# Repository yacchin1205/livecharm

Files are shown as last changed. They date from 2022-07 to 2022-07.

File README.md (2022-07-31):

# このリポジトリについて

*TBD*

# 必要パーツ

- Adafruit Feather RP2040 - ¥2,211
  https://www.switch-science.com/catalog/7216/
- リチウムイオンポリマー電池110mAh - ¥1,094
  https://www.switch-science.com/catalog/3166/
- MAX98357A搭載 I2S 3W D級アンプボード - ¥1,309
  https://www.switch-science.com/catalog/2749/
- uxcell オーバル 1W 8オーム マグネットスピーカー 4個 - ¥628
  https://www.amazon.co.jp/gp/product/B017IIV8KM/ 
- KKHMF TTP223 静電容量式 タッチスイッチ 10個 - ¥539
  https://www.amazon.co.jp/gp/product/B079BKVT98/

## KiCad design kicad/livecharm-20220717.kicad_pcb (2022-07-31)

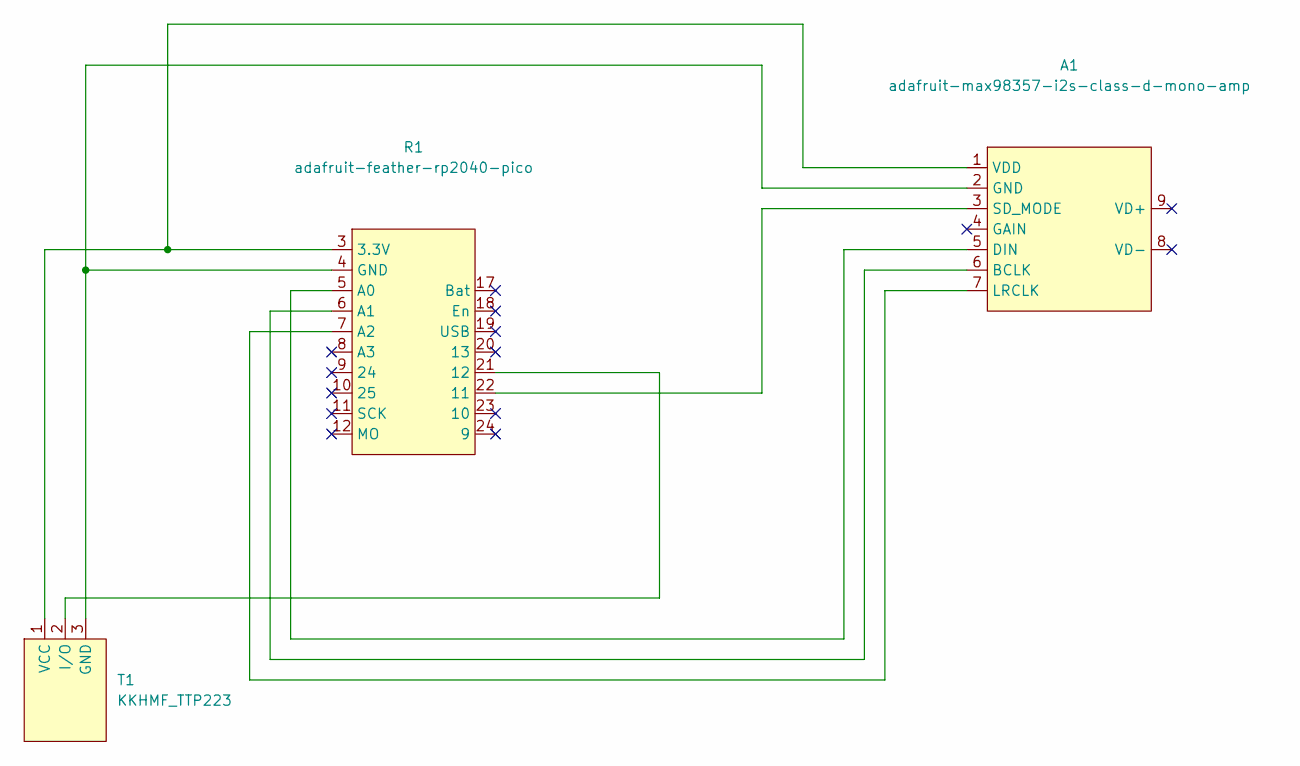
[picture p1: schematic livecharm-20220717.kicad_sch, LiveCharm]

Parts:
A1: adafruit-max98357-i2s-class-d-mono-amp
R1: adafruit-feather-rp2040-pico
T1: KKHMF_TTP223

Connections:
unnamed: A1.1 (VDD), R1.3 (3.3V), T1.1 (VCC)
unnamed: A1.2 (GND), R1.4 (GND), T1.3 (GND)
unnamed: A1.3 (SD_MODE), R1.22 (11)
unnamed: A1.5 (DIN), R1.5 (A0)
unnamed: A1.6 (BCLK), R1.6 (A1)
unnamed: A1.7 (LRCLK), R1.7 (A2)
unnamed: R1.21 (12), T1.2 (I/O)

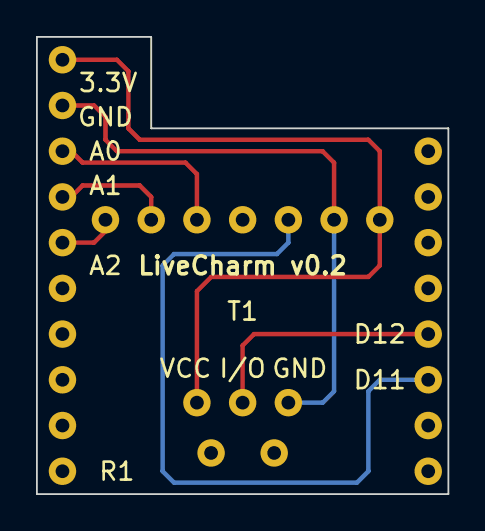
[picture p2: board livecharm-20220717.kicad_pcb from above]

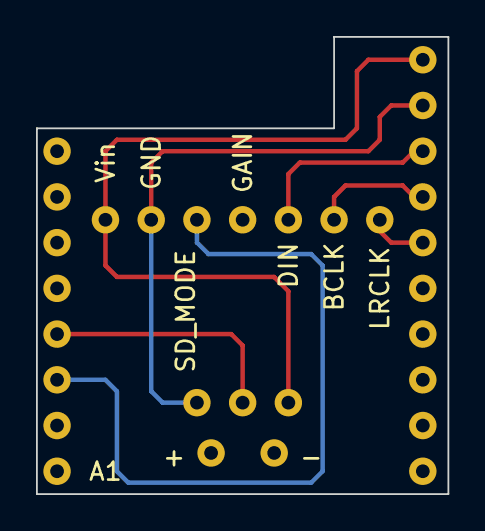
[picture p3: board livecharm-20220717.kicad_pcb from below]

Board: 2 copper layers, 22.9 x 25.4 mm, 3 parts (2 on the bottom side), 7 nets.

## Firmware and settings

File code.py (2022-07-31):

import digitalio
import audiocore
import audiopwmio
import board
import array
import time
import math
import os
import alarm
import audiobusio
import random
import re
import errno

DEFAULT_LIGHT_WAKEUP_SEC = 30
MAX_SLEEP_COUNT = 20
AUDIO_DIR = './audio'

# ---- Interface関係の定義
WAKE_PIN = board.D12
SHUTDOWN_PIN = board.D11

def open_dac():
    # Feather RP2040
    return audiobusio.I2SOut(board.A1, board.A2, board.A0)

# ---- Deep Sleep関係の処理
def get_pin_alarm():
    return alarm.pin.PinAlarm(pin=WAKE_PIN, value=True, pull=True)

def enter_deep_sleep():
    pin_alarm = get_pin_alarm()
    alarm.exit_and_deep_sleep_until_alarms(pin_alarm)
    # Deep Sleep後は続行されない

# ---- Light Sleep関係の処理
def enter_light_sleep():
    pin_alarm = get_pin_alarm()
    time_alarm = alarm.time.TimeAlarm(monotonic_time=time.monotonic() + DEFAULT_LIGHT_WAKEUP_SEC)
    triggered_alarm = alarm.light_sleep_until_alarms(pin_alarm, time_alarm)
    return not is_time_alarm(triggered_alarm)

def is_time_alarm(wake_alarm):
    return wake_alarm is not None and isinstance(wake_alarm, alarm.time.TimeAlarm)

# ---- Audio関係の処理
class AudioFiles:
    def __init__(self, audio_dir):
        self.waves = {}
        self.files = self.load_files(audio_dir)
        self.max_index = max([max([max(r[0], r[1]) for r in rset]) if rset is not None and len(rset) > 0 else 0 for rset, _ in self.files])

    def load_files(self, audio_dir):
        if not audio_dir.endswith('/'):
           audio_dir += '/'
        try:
            files = []
            for file in os.listdir(audio_dir):
                if file.startswith('.'):
                    print('File ignored(dot file): ', file)
                    continue
                m = re.match(r'.+(\.[a-zA-Z0-9]+)', file)
                if m is None or m.group(1).lower() != '.wav':
                    print('File ignored(must be .wav file): ', file)
                    continue
                entry = self.file_entry(audio_dir, file)
                files.append((entry, audio_dir + file))
            return files
        except OSError as e:
            if e.args[0] == errno.ENOENT:
                print('Directory not exists:', audio_dir)
                return []
            raise e

    def file_entry(self, audio_dir, file):
        prefix = re.match(r'([0-9\-_]+)[\-_].+', file)
        if prefix is None:
            return None
        return [self._parse_range(elem) for elem in prefix.group(1).split('_')]

    def get_wave(self, index):
        path = self._resolve_wave(index)
        if path is None:
            return None
        if path in self.waves:
            return self.waves[path]
        print('Loading...', path)
        data = open(path, "rb")
        wave = audiocore.WaveFile(data)
        self.waves[path] = wave
        return wave

    def has(self, index):
        return index <= self.max_index

    def _resolve_wave(self, index):
        if index == 0 and all([r is None for r, _ in self.files]):
            print('Randomize waves...')
            _, path = random.choice(self.files)
            return path
        cands = [(r, path) for r, path in self.files if self._is_match(r, index)]
        print('Selecting from', cands, '#{}'.format(index))
        if len(cands) == 0:
            if index > 0:
                return self._resolve_wave(index - 1)
            return None
        _, path = random.choice(cands)
        return path

    def _is_match(self, rset, index):
        if rset is None:
            return False
        for r in rset:
            rmin, rmax = r
            if (rmin <= index) and (index <= rmax):
                return True
        return False

    def _parse_range(self, elem):
        m = re.match(r'([0-9]+)\-([0-9]+)', elem)
        if m is not None:
            return (int(m.group(1)), int(m.group(2)))
        m = re.match(r'[0-9]+', elem)
        if m is not None:
            index = int(elem)
            return (index, index)
        return None

# Audioの再生完了待ち
def wait_audio(dac, button):
    time.sleep(0.5)
    if not dac.playing:
        return button.value
    v = False
    while dac.playing:
        if v == False and button.value:
            print('Pressed(while playing)')
            v = True
    return v

# Audioのタッチ操作受付処理
def loop_waves(dac, audio_files, sd_mode):
    with digitalio.DigitalInOut(WAKE_PIN) as button:
        button.switch_to_input(pull=digitalio.Pull.DOWN)

        sleep_count = MAX_SLEEP_COUNT
        index = 0
        sd_mode.value = True
        dac.play(audio_files.get_wave(index))
        next_play = wait_audio(dac, button)
        sd_mode.value = False
        index += 1
        if not audio_files.has(index):
            index = 0

        # ボタンが押されるまで待つ ... 一定時間に押されなければ
        # この処理は抜ける
        while sleep_count > 0:
            if next_play or button.value:
                print('Pressed')
                sd_mode.value = True
                dac.play(audio_files.get_wave(index))
                next_play = wait_audio(dac, button)
                sd_mode.value = False
                index += 1
                if not audio_files.has(index):
                    index = 0
                sleep_count = MAX_SLEEP_COUNT
            sleep_count -= 1
            time.sleep(0.1)

# ---- Main
audio_files = AudioFiles(AUDIO_DIR)
if len(audio_files.files) == 0:
    print('No audio files')

else:
    with digitalio.DigitalInOut(SHUTDOWN_PIN) as sd_mode:
        sd_mode.switch_to_output(value=False)
        with open_dac() as dac:
            loop_waves(dac, audio_files, sd_mode)

            # タッチ操作でLight Sleepが解除された場合は
            # 繰り返し待つ
            while enter_light_sleep():
                loop_waves(dac, audio_files, sd_mode)

# しばらく操作がなかったのでDeep Sleep
enter_deep_sleep()

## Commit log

2022-07-31 Add CAD files
    [livecharm-20220717.kicad_pcb, livecharm-20220717.kicad_sch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]
2022-07-31 Add gerber file
